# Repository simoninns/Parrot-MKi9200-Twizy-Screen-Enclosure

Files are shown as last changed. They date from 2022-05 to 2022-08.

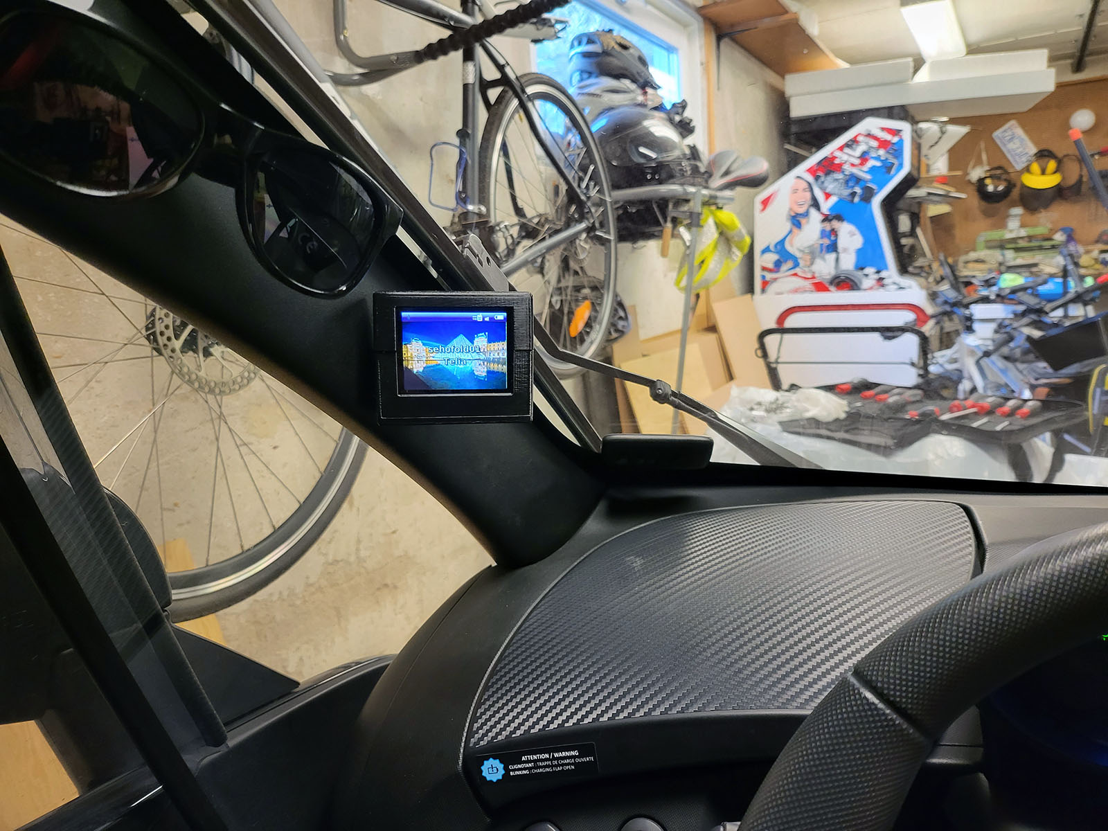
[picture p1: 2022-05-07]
images/20220507_164905.jpg

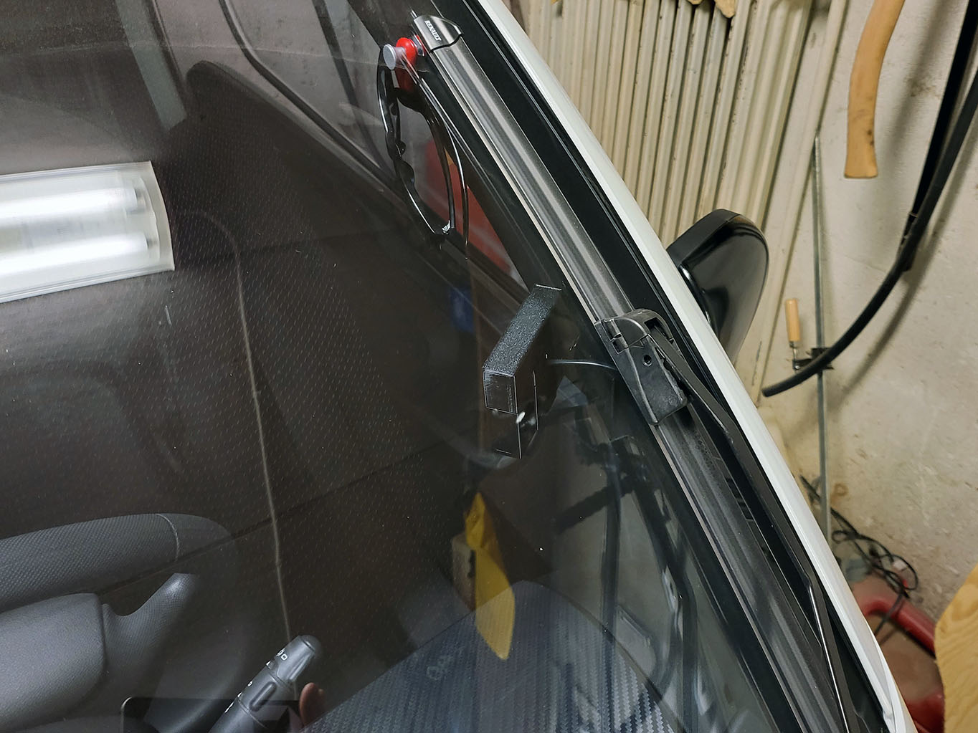
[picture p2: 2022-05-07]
images/20220507_165011.jpg

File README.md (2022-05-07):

# Parrot MKi9200 Twizy Screen Enclosure
## Overview
This project provides a Parrot MKi9200 screen enclosure for mounting the LCD display in the Renault Twizy.  The LCD is removable, but the original mount is flimsy and easily broken.  This mount makes the display more perminant and provides better protection along with a more study mounting surface.

This project is open-source.  You can find the OpenSCAD source here: https://github.com/simoninns/Parrot-MKi9200-Twizy-Screen-Enclosure

The OpenSCAD source also includes a mock-up of the actual display to make modification to the design easier.

## Printing instructions
The model has been printed and tested on the Prusa MK3S/MMU2S printer using Prusament PETG filament. All parts fit on a 20x20 printing bed.

### Recommended print settings

Print settings (for Prusa Slicer) are the same for all included parts:

* Material: PETG
* Layer: 0.30mm
* Infill: 25%
* Supports: No Supports

# Assembly
Connect the display the cable bracket and run the cable up the bracket towards the top of the LCD.  Insert the display and bracket into the lower case part; it should push in firmly.

Route the cable out of the back of the lower holder and push the upper case down onto the display. The two tabs at the back will lock into place holding the two case parts firmly together.

Apply some double-sided foam mirror tape to the case and affix to the Renault Twizy.  See the included pictures for the suggested mounting location.

## Author
This project is designed and maintained by Simon Inns.

# Licensing
## OpenSCAD source files - software license (GPLv3)

    This is free software: you can redistribute it and/or modify
    it under the terms of the GNU General Public License as published by
    the Free Software Foundation, either version 3 of the License, or
    (at your option) any later version.
    
    This program is distributed in the hope that it will be useful,
    but WITHOUT ANY WARRANTY; without even the implied warranty of
    MERCHANTABILITY or FITNESS FOR A PARTICULAR PURPOSE.  See the
    GNU General Public License for more details.
    
    You should have received a copy of the GNU General Public License
    along with this program.  If not, see <http://www.gnu.org/licenses/>.

## Non-source-code media - Creative Commons license (Creative Commons BY-SA 4.0)
Please see the following link for details: https://creativecommons.org/licenses/by-sa/4.0/

You are free to:

Share - copy and redistribute the material in any medium or format
Adapt - remix, transform, and build upon the material
for any purpose, even commercially.

This license is acceptable for Free Cultural Works.

The licensor cannot revoke these freedoms as long as you follow the license terms.

Under the following terms:

Attribution - You must give appropriate credit, provide a link to the license, and indicate if changes were made. You may do so in any reasonable manner, but not in any way that suggests the licensor endorses you or your use.

ShareAlike - If you remix, transform, or build upon the material, you must distribute your contributions under the same license as the original.

No additional restrictions - You may not apply legal terms or technological measures that legally restrict others from doing anything the license permits.

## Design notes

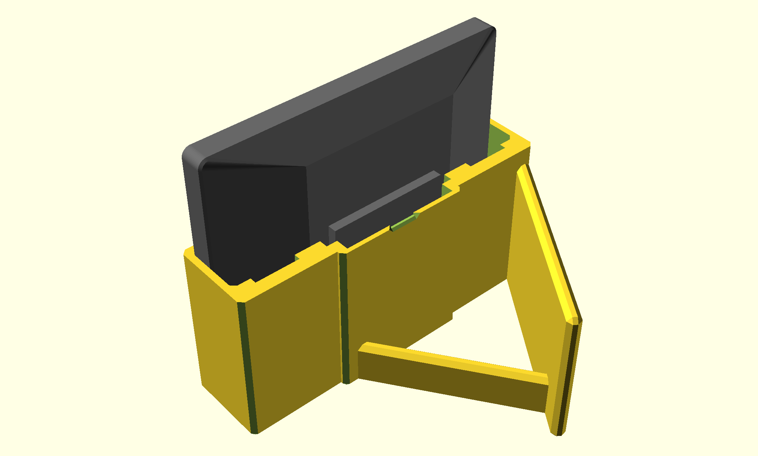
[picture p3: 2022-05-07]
images/lower_case_back.png

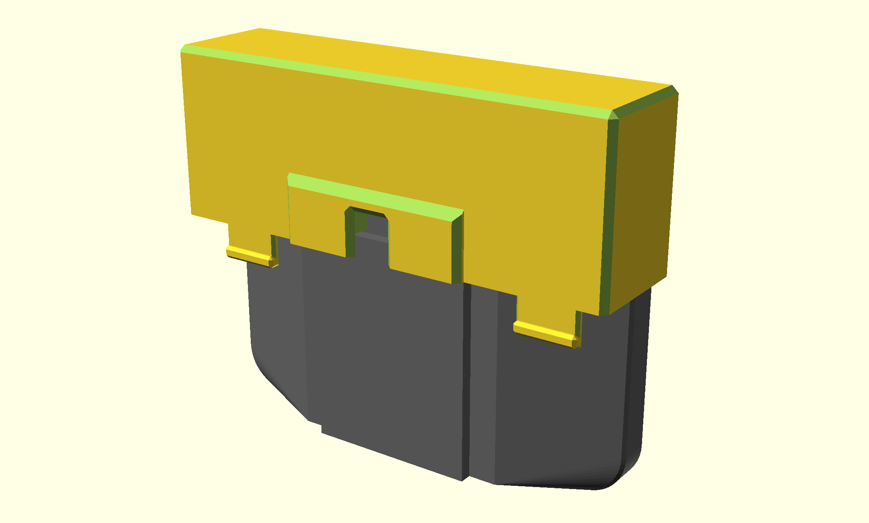
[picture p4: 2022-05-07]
images/upper_case_back.png

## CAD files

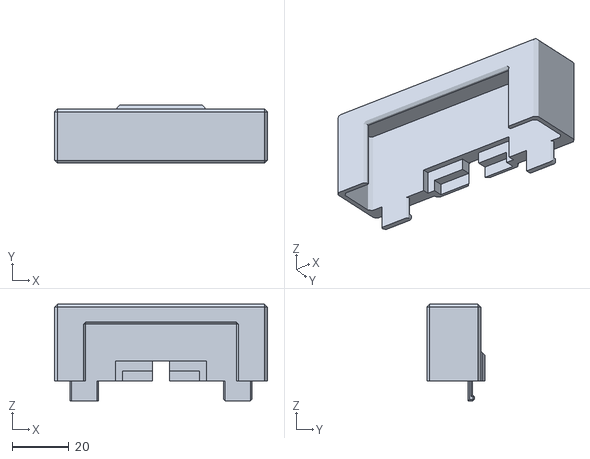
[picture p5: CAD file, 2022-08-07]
stl/upper_case.stl
75.0 x 20.5 x 34.0

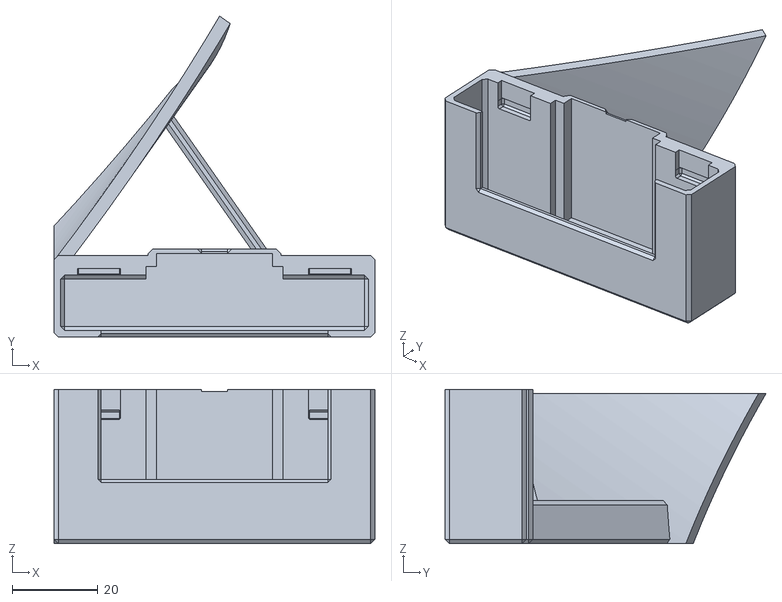
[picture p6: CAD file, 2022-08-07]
stl/lower_case.stl
75.0 x 75.0 x 36.0

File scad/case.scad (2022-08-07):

/************************************************************************

    case.scad
    
    Parrot MKi9200 Twizy Screen Enclosure
    Copyright (C) 2022 Simon Inns
    
    This is free software: you can redistribute it and/or modify
    it under the terms of the GNU General Public License as published by
    the Free Software Foundation, either version 3 of the License, or
    (at your option) any later version.
    
    This program is distributed in the hope that it will be useful,
    but WITHOUT ANY WARRANTY; without even the implied warranty of
    MERCHANTABILITY or FITNESS FOR A PARTICULAR PURPOSE.  See the
    GNU General Public License for more details.
    
    You should have received a copy of the GNU General Public License
    along with this program.  If not, see <http://www.gnu.org/licenses/>.
	
    Email: simon.inns@gmail.com
    
************************************************************************/

include <BOSL/constants.scad>
use <BOSL/transforms.scad>
use <BOSL/shapes.scad>

module screen_cutout()
{
    move([0,-7,32.5]) cuboid([49 + 4,4,37 + 4], chamfer=0);
    move([0,-9.25,32.5]) cuboid([49 + 6,4,37 + 6], chamfer=1); // Screen
}

module car_mount()
{
    move([-11,6,-3]) {
        move([-2.5,38,0]) rotate([0,0,-55]) cuboid([44,3,10], center=false, chamfer=1); // Strength

        // Curved mounting with 200mm diameter curve
        difference() {
            union() {
                move([-138, 100, 40]) {
                    rotate ([45,-45,0]) {
                        difference() {
                            cyl(h=100,d=300, $fn=200);
                            cyl(h=100 + 4,d=300 - 6, $fn=200);
                        }
                    }
                }

                difference() {
                    move([-25,9,16]) cuboid([3,10,32], chamfer=1, edges=EDGE_BOT_LF);
                    move([-138, 100, 40]) rotate ([45,-45,0]) cyl(h=100 + 4,d=300 - 6, $fn=200);
                }
            }

            move([0,0,-100]) cuboid([800,500,200]);
            move([-176.5,0,0]) cuboid([300,500,400]);
            move([0,0,100]) cuboid([100,400,130]);
        }

        
    }
}

module lower_case()
{
    move([0,0,0]) {
        difference() {
            union() {
                move([0,1.5,18-3]) cuboid([75,19,36], chamfer=1, edges=EDGES_Z_ALL+EDGES_X_BOT+EDGES_Y_BOT);
                move([0,10.5,15]) cuboid([27 + 4,4,36], chamfer=1, edges=EDGES_Z_ALL+EDGES_X_BOT+EDGES_Y_BOT);
                car_mount();
            }
            move([0,1.5 - 1.5,18 - 0 ]) cuboid([75 - 3,19 - 6,36], chamfer=1, edges=EDGES_Z_ALL+EDGES_X_BOT+EDGES_Y_BOT);
            move([0,6.5,18]) cuboid([32,4,36]); // Bracket clearance
            move([0,9.5,18]) cuboid([27,4,36]); // Bracket clearance

            move([0,8,22 + 28.5]) cuboid([6,8,36], chamfer=0); // Cable exit
            move([0,15.5,23 + 27]) cuboid([8,8,36], chamfer=1); // Cable exit chamfer

            screen_cutout();

            // Clips
            move([27,7.24,30.5]) cuboid([10,1.5,8]);
            move([27,7.5,27]) cuboid([10.5,2.5,2.5], chamfer=0.5, edges=EDGES_Z_ALL+EDGES_Y_TOP+EDGES_Y_BOT+EDGES_X_BOT+EDGES_X_TOP);
            
            move([-27,7.24,30.5]) cuboid([10,1.5,8]);
            move([-27,7.5,27]) cuboid([10.5,2.5,2.5], chamfer=0.5, edges=EDGES_Z_ALL+EDGES_Y_TOP+EDGES_Y_BOT+EDGES_X_BOT+EDGES_X_TOP);
        }
    }
}

module upper_case()
{
    move([0,0,0]) {
        difference() {
            union() {
                move([0,1.5,46.5]) cuboid([75,19,27], chamfer=1, edges=EDGES_Z_ALL+EDGES_X_TOP+EDGES_Y_TOP);
                move([0,10.5,38]) cuboid([27 + 4,4,10], chamfer=1, edges=EDGES_Z_ALL+EDGES_X_TOP);

                // Add extra overhang to remove need for a support when printing
                move([0,10,42.5]) cuboid([27 + 4,3,3], chamfer=1, edges=EDGES_X_TOP);
            }
            move([0,1.5 - 1.5,42 - 2]) cuboid([75 - 3,19 - 6,36], chamfer=1, edges=EDGES_Z_ALL+EDGES_X_BOT+EDGES_Y_BOT);
            move([0,6.5,22]) cuboid([32,4,36]); // Bracket clearance
            move([0,9.5,18.5]) cuboid([27,4,36]); // Bracket clearance

            move([0,8,22]) cuboid([6,8,36], chamfer=0); // Cable exit
            move([0,15.5,23]) cuboid([8,8,36], chamfer=1); // Cable exit chamfer

            screen_cutout();
        }

        // Clips
        move([27,7.25,29.5]) cuboid([10,1.5,7], chamfer=0.5, edges=EDGES_Z_ALL+EDGES_Y_BOT);
        move([27,7.75,27]) cuboid([10,2,2], chamfer=0.5, edges=EDGES_Z_ALL+EDGES_Y_TOP+EDGES_Y_BOT+EDGES_X_BOT+EDGES_X_TOP);
        
        move([-27,7.25,29.5]) cuboid([10,1.5,7], chamfer=0.5, edges=EDGES_Z_ALL);
        move([-27,7.75,27]) cuboid([10,2,2], chamfer=0.5, edges=EDGES_Z_ALL+EDGES_Y_TOP+EDGES_Y_BOT+EDGES_X_BOT+EDGES_X_TOP);
    }
}

module render_lower_case(toPrint)
{
    if (toPrint) {
        move([0,0,3]) lower_case();
    } else {
        lower_case();
    }
}

module render_upper_case(toPrint)
{
    if (toPrint) {
        move([0,-30,60]) xrot(180) upper_case();
    } else {
        move([0,0,0.25]) upper_case();
    }
}

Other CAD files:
scad/main.scad
scad/screen.scad

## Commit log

2022-05-07 Push of the initial project files
    [case.scad, lower_case.stl, main.scad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]
2022-05-07 Added pictures and CAD renderings
2022-08-07 Added curve to lower case to better fit the car
    [case.scad, lower_case.stl, upper_case.stl]
